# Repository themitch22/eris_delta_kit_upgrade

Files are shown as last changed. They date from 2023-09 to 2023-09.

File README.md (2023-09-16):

*********************
9/18/23
Forked design: Adding my upgraded parts to mount a new Voron V0 OLED display controller, Raspberry Pi, and an SKR Mini E3 V3 control board to run Klipper firmware.

*********************

ERIS Delta 3D Printer
=====================

ERIS is an affordable desktop 3D printer built by SeeMeCNC.  We designed this machine to be fast, easy to use and much more affordable than any of our previous designs.  

3/2/16
DIR Repetier-Firmware-092.2-ERIS is workign on prototypes

3/3/16
DIR Repetier-Firmware-092.2-ERIS-ii2dh is modified 092 firmware from UltiMachine for accelerometer probing on new hotend PCB board

####

Case fan goes to fan port 2
Hotend fan goes to fan port 1

Red motor wire to right (opposite of the USB side of mini rabmo)

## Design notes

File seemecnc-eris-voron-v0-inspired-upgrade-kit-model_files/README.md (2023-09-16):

9/18/23
Forked design: Adding my upgraded parts to mount a new Voron V0 OLED display controller, Raspberry Pi, and an SKR Mini E3 V3 control board to run Klipper firmware.

The SeeMeCNC Eris, released in 2016, was a ready to print out of the box mini delta printer made with injection molded parts and custom extruder hotend parts almost entirely US-made. They even sold these printers at retail stores like Microcenter! 

I loved this printer, but it had some major issues: 

    The ATMEGA2560 based Rambo Mini board with Repetier limits a delta printers speed and precision
    The HE280 based PCB on the effector used an accelerometer to detect nozzle probes for auto-calibration. It was a very advanced idea for 2016, but with modern firmware, delta-calibration techniques are way more reliable. For this mod, I have stuck with Manual Delta Calibration in Klipper and it's been super reliable for first layers. 
    The stock hotend and single 3010 fan was lacking. It used a bowden tube to a steel heatbreak (partially all metal) that attached the hotend to the effector PCB, the heater cartridge was a power resistor (about 20W), the single 3010 fan sucked air past the heatsync and it was also the part cooling with a shroud. The original print head did not have adequate heating and cooling.
    The Eris had no LCD controller. It had a light up logo on front which I think was supposed to be an addressable LED, but all the control was done through MatterControl (Matterhackers) so it wasn't really portable without a PC attached. 

Parts Needed and Instructions (links to vendors and files)

    Original SeeMeCNC Eris - I have not found these on ebay but there are a few still floating around or collecting dust on a shelf.
    BTT SKR Mini E3 V3 control board - It's about the same footprint as the Rambo Mini but has way more power and IO. A SKR Pico would work as well but the connectors are on the edge which might interfere with the case. You will also want an external microSD connector pass through one of the holes and stuck to the outside of the case, this helps flash board firmware from Klipper.
    SKR Mini Mounting Bracket - by w0nd4bra this bracket barely fits where the Rambo Mini use to slot in. I checked for clearance and marked and drilled two holes for M3x8 screws and used heat set inserts to fasten it to the shelf. You might want to use VHB tape instead. It will interfere with the corner screw bosses, you might have to sand that away. See the pictures for how I mounted it. 
    Raspberry Pi 3B or equivalent - These are still hard to get, you can also use the BTT Pi V1.2, the mount I designed will fit standard a Pi 3/4B, you will need to glue and heat insert the standoffs. It clips into the frame of the LCD mount backside. It provides a pass-through hole for the USB cable.
    Voron V0.2 Mini OLED Display Controller (designed by Timmit99)- This controller works with Klipper with a short USB cable to the Pi (I cut the micro USB side and soldered it to a dupont connector). You will need to print the Voron V0.2 display faceplate, knob, and diffuser (or hotglue like I used) using M2x10 self-tapping screws to mount into my custom Eris LCD mount. The LCD mount should slot right into the base like the original Eris logo. 
    E3D Revo Micro 12V kit - The Revo was the smallest, lightest, easiest hotend for the Eris. The top and base mount with M3x8 screws into the plastic. The Revo wires slip through the back side cut out. I initially worked with Hotends.com to come up with a custom mount for their J-head Farmer hotend but it was too heavy. The E3D Revo comes with a 5V fan which needs a step-down converter I just soldered into the existing whip fan connections. The current design you will need to sand down the fan shroud to not interfere with the 3010 blowers (see picture). I would also highly recommend using capricorn XS tube to reduce the long bowden issues like retraction, I can get away with 4mm retractions with this setup. Also check if you have the original EZstruder, you really want the latest SeeMeCNC EZR extruder it honestly works great as is. 
    GDSTime 3010 12V Blower Fans - These part cooling fans really make a huge difference in the performance of the Eris. My effector mount base and top has M2 x 10 screw points for mounting them and a duct that blows down on to the part (I found no need for a nozzle)
    I used the existing whip but removed the original connectors and soldered them to a 8-pin GX16 connector (Use this guide for wiring) mounted to a hole I drilled in the case, I soldered and crimped the other side of the whip to the components on the effector side. This allows you to easily remove the whole assembly for troubleshooting and travel. You will need JST-XH crimps connectors for the BTT board and maybe some dupont 2.54 pitch connectors and crimpers.

Basically if you've build a Voron V0.1/0.2 you can handle this mod. It is basically a Voron V0 delta but not nearly as rigid or fast. 

Please comment or message me and I will publish the Klipper config files needed for the Eris. 

The printing results are incredible considering the age and plastic shell of this delta. It is limited to 500mm/s2 accels and 125mm/s rapids, which is quite slow for modern standards but you can't beat the portability and looks of this little printer. 

If you have an Eris and want to do this mod, please message me I will try to help you with whatever I can. STEP files included if you need to modify something, I can provide Fusion 360 files if needed (they're too messy to publish).

Pulled files from my Printables repo:
https://www.printables.com/model/581542-seemecnc-eris-voron-v0-inspired-upgrade-kit

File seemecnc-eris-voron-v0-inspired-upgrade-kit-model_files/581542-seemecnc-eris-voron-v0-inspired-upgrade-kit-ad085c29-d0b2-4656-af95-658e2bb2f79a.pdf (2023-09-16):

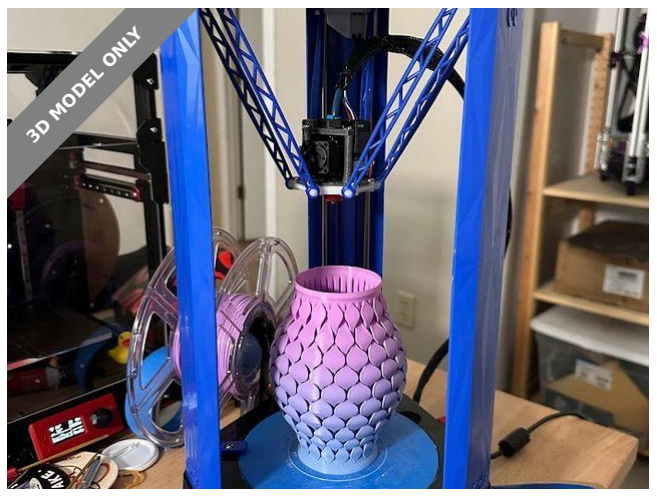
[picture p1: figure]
3D MODEL ONLY

### Summary

The ultimate upgrade package for your SeeMeCNC Eris mini delta printer (2016)

3D Printers (https://printables.com/model?categoryId=1) > Other Printer Parts & Upgrades (https://printables.com/model?categoryId=2)

Tags: raspberry | pi | eris | klipper | voron | seemecnc | v0

The SeeMeCNC Eris, (https://www.seemecnc.com/products/eris-desktop-3d-printer) released in 2016, was a ready to print out of the box mini delta printer made with injection molded parts and custom extruder hotend parts almost entirely US-made. They even sold these printers at retail stores like Microcenter!

I loved this printer, but it had some major issues:

The ATMEGA2560 based Rambo Mini board with Repetier limits a delta printers speed and precision
The HE280 based PCB on the effector used an accelerometer to detect nozzle probes for auto-calibration. It was a very advanced idea for 2016, but with modern firmware, delta-calibration techniques are way more reliable. For this mod, I have stuck with Manual Delta Calibration in Klipper and it's been super reliable for first layers.
The stock hotend and single 3010 fan was lacking. It used a bowden tube to a steel heatbreak (partially all metal) that attached the hotend to the effector PCB, the heater cartridge was a power resistor

Mitch 3D (https://printables.com/@Mitch3D)

### SeeMeCNC Eris

### Voron V0-Inspired

### Upgrade Kit

VIEW IN BROWSER (https://printables.com/model/581542-seemecnc-eris-voron-v0-inspired-upgrade-kit)

updated 13. 9. 2023 | published 13. 9. 2023

•

•

•

(about 20W), the single 3010 fan sucked air past the heatsync and it was also the part cooling with a shroud. The original print head did not have adequate heating and cooling.
The Eris had no LCD controller. It had a light up logo on front which I think was supposed to be an addressable LED, but all the control was done through MatterControl (https://www.matterhackers.com/store/l/mattercontrol/sk/MKZGTDW6) (Matterhackers) so it wasn't really portable without a PC attached.

Parts Needed and Instructions (links to vendors and files)

Original SeeMeCNC Eris - I have not found these on ebay but there are a few still floating around or collecting dust on a shelf.
BTT SKR Mini E3 V3 control board (https://biqu.equipment/products/bigtreetech-skr-mini-e3-v2-0-32-bit-control-board-for-ender-3) - It's about the same footprint as the Rambo Mini but has way more power and IO. A SKR Pico would work as well but the connectors are on the edge which might interfere with the case. You will also want an external microSD connector (https://a.co/d/5BjRwnt) pass through one of the holes and stuck to the outside of the case, this helps flash board firmware from Klipper.
SKR Mini Mounting Bracket (https://www.printables.com/model/172510-bigtreetech-skr-mini-e3-v2030-bracket) - by w0nd4bra (https://www.printables.com/@w0nd4bra) this bracket barely fits where the Rambo Mini use to slot in. I checked for clearance and marked and drilled two holes for M3x8 screws and used heat set inserts to fasten it to the shelf. You might want to use VHB tape instead. It will interfere with the corner screw bosses, you might have to sand that away. See the pictures for how I mounted it.
Raspberry Pi 3B or equivalent - These are still hard to get, you can also use the BTT Pi V1.2, the mount I designed will fit standard a Pi 3/4B, you will need to glue and heat insert the standoffs. It clips into the frame of the LCD mount backside. It provides a pass-through hole for the USB cable.
Voron V0.2 Mini OLED Display Controller (https://west3d.com/products/v0-display) (designed by Timmit99)- This controller works with Klipper with a short USB cable to the Pi (I cut the micro USB side and soldered it to a dupont connector). You will need to print the Voron V0.2 display faceplate, knob, and diffuser (https://github.com/VoronDesign/Voron-0/tree/Voron0.2r1/STLs/Display) (or hotglue like I used) using M2x10 self-tapping screws to mount into my custom Eris LCD mount. The LCD mount should slot right into the base like the original Eris logo.
E3D Revo Micro 12V kit (https://e3d-online.com/products/revo-micro) - The Revo was the smallest, lightest, easiest hotend for the Eris. The top and base mount with M3x8 screws into the plastic. The Revo wires slip through the back side cut out. I initially worked with Hotends.com to come up with a custom mount for their J-head Farmer hotend (https://hotends.com/printer-parts/hotends/j-head-farmer-hotend/) but it was too heavy. The E3D Revo comes with a 5V fan which needs a step-down converter I just soldered into the existing whip fan connections. The current design

you will need to sand down the fan shroud to not interfere

with the 3010 blowers (see picture). I would also highly
recommend using capricorn XS tube to reduce the long bowden

•

•

•

•

•

•

•

### Model files

issues like retraction, I can get away with 4mm retractions with this setup. Also check if you have the original EZstruder, you really want the latest SeeMeCNC EZR extruder (https://www.seemecnc.com/products/ezrstruder) it honestly works great as is. GDSTime 3010 12V Blower Fans (https://a.co/d/asESusC) - These part cooling fans really make a huge difference in the performance of the Eris. My effector mount base and top has M2 x 10 screw points for mounting them and a duct that blows down on to the part (I found no need for a nozzle)
I used the existing whip but removed the original connectors and soldered them to a 8-pin GX16 connector (https://a.co/d/5zVXuh1) (Use this guide for wiring) (https://hotends.com/kb/eris-3d-printer/) mounted to a hole I drilled in the case, I soldered and crimped the other side of the whip to the components on the effector side. This allows you to easily remove the whole assembly for troubleshooting and travel. You will need JST-XH crimps connectors (https://a.co/d/ebk87RT) for the BTT board and maybe some dupont 2.54 pitch connectors and crimpers.

Basically if you've build a Voron V0.1/0.2 you can handle this mod. It is basically a Voron V0 delta but not nearly as rigid or fast.

Please comment or message me and I will publish the Klipper config files needed for the Eris.
The printing results are incredible considering the age and plastic shell of this delta. It is limited to 500mm/s2 accels and 125mm/s rapids, which is quite slow for modern standards but you can't beat the portability and looks of this little printer.

If you have an Eris and want to do this mod, please message me I will try to help you with whatever I can. STEP files included if you need to modify something, I can provide Fusion 360 files if needed (they're too messy to publish).

•

•

eris-lcd-mount-pi-attachment-standoff.3mf

eris-revo-3010-effector-mount-top.3mf

### License

This work is licensed under a
Creative Commons (4.0 International License)

Attribution (http://creativecommons.org/licenses/by/4.0/)

✖ | Sharing without ATTRIBUTION
✔ | Remix Culture allowed
✔ | Commercial Use
✔ | Free Cultural Works
✔ | Meets Open Definition

eris-mini-lcd-mount.3mf

eris-lcd-mount-pi-attachment.step

eris-revo-3010-effector-mount-base.3mf

eris-mini-lcd-mount-v5.step

eris-revo-3010-effector-mount.step

eris-lcd-mount-pi-attachment-body.3mf

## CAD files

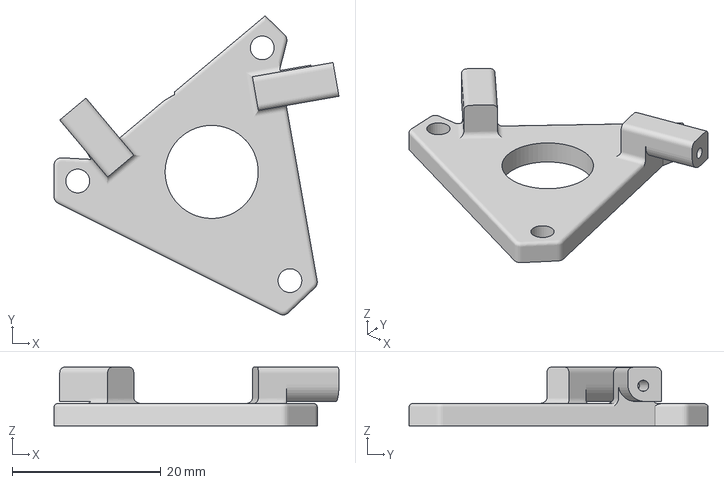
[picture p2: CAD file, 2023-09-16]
seemecnc-eris-voron-v0-inspired-upgrade-kit-model_files/Eris Revo 3010 Effector Mount Top.3mf
38.3 x 40.2 x 7.87 mm

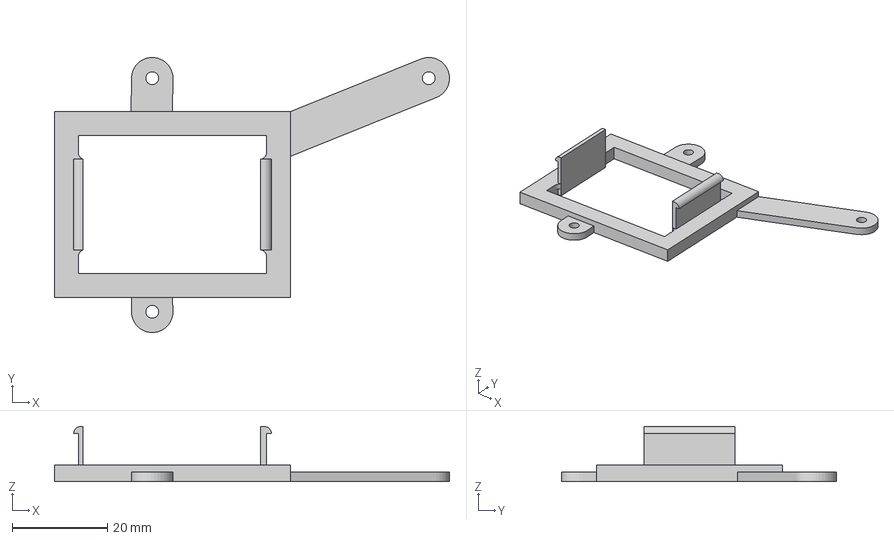
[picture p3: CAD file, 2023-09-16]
seemecnc-eris-voron-v0-inspired-upgrade-kit-model_files/Eris LCD Mount Pi Attachment Body.3mf
82.8 x 57.7 x 11.6 mm

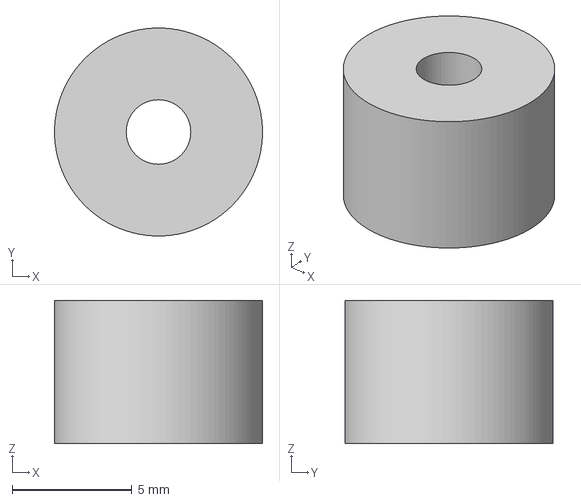
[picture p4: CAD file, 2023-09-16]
seemecnc-eris-voron-v0-inspired-upgrade-kit-model_files/Eris LCD Mount Pi Attachment Standoff.3mf
8.70 x 8.70 x 6.00 mm

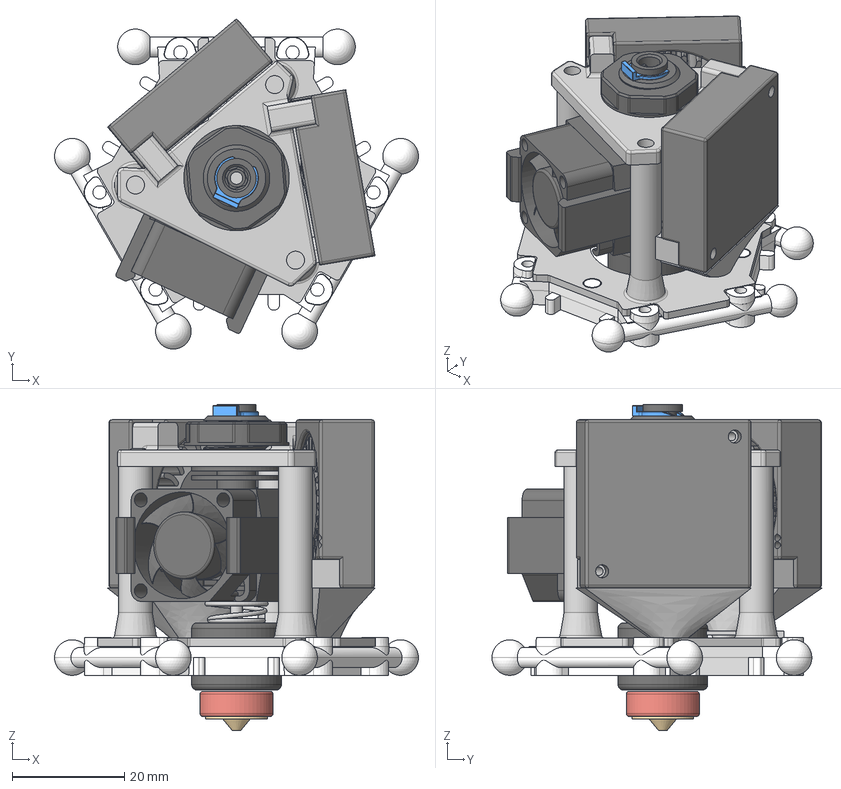
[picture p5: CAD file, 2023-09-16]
seemecnc-eris-voron-v0-inspired-upgrade-kit-model_files/Eris Revo 3010 Effector Mount.step
64.8 x 58.8 x 58.1 mm
71200 HE280 Assembly_86005 Platform
71200 HE280 Assembly_Blower 30mm x 30mm x 10mm x 2
Heatblock
Nozzle
Threaded_Nut
Spring
Heatbreak
Heatsink
Cable_Exit
Coupling_Clip
20x20x10_Fan
Fan_Mount
Coupling

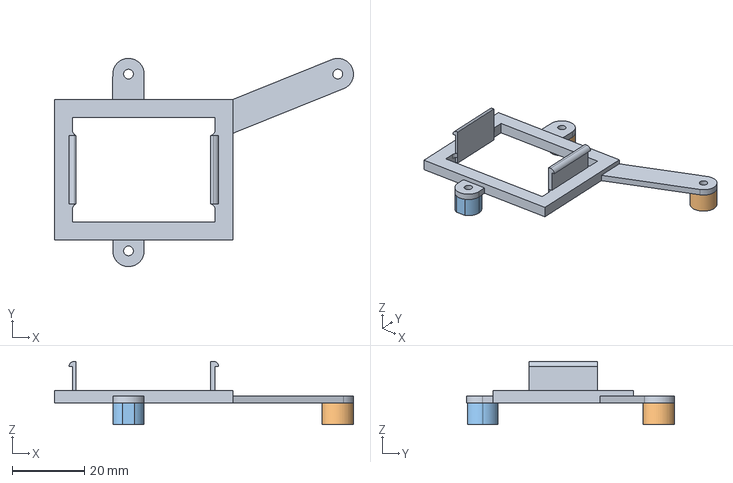
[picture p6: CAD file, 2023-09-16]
seemecnc-eris-voron-v0-inspired-upgrade-kit-model_files/Eris LCD Mount Pi Attachment.step
82.8 x 57.7 x 17.6 mm

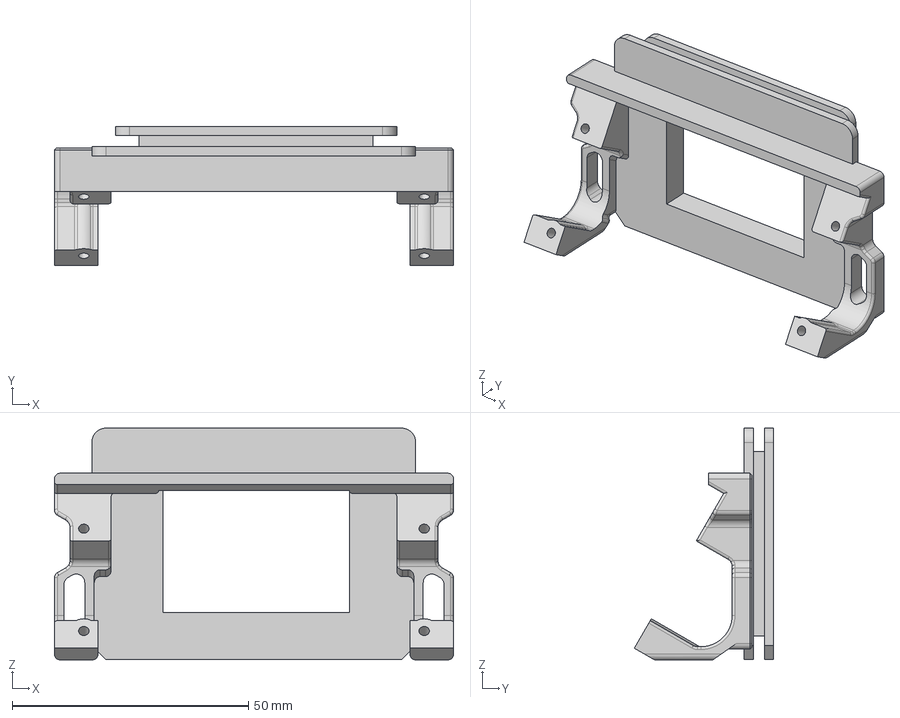
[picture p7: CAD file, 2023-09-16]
seemecnc-eris-voron-v0-inspired-upgrade-kit-model_files/Eris Mini LCD mount v5.step
84.4 x 29.5 x 49.0 mm
Display Left Foot
Display Right Foot

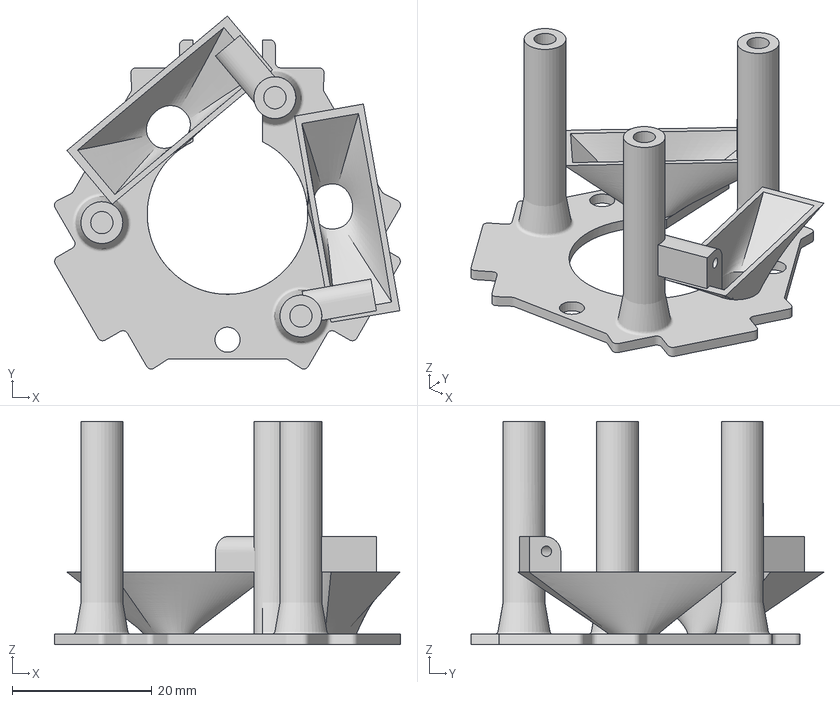
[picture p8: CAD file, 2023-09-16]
seemecnc-eris-voron-v0-inspired-upgrade-kit-model_files/Eris Revo 3010 Effector Mount Base.3mf
49.6 x 50.6 x 32.0 mm

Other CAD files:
seemecnc-eris-voron-v0-inspired-upgrade-kit-model_files/Eris Mini LCD Mount.3mf

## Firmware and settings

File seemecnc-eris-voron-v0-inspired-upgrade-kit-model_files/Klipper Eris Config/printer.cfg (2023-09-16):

# This file is an example config file for linear delta style printers.
# One may copy and edit this file to configure a new delta printer.

# DO NOT COPY THIS FILE WITHOUT CAREFULLY READING AND UPDATING IT
# FIRST. Incorrectly configured parameters may cause damage.

# See docs/Config_Reference.md for a description of parameters.

# ================= Eris Repetier Specs ======================
#define DELTA_DIAGONAL_ROD 134.9  // 134.58 early measurement
#define DELTA_MAX_RADIUS 65  // max printable area allowed by firmware
#define PRINTER_RADIUS 98.38  //PRINTER_RADIUS-END_EFFECTOR_HORIZONTAL_OFFSET-CARRIAGE_HORIZONTAL_OFFSET
#define Z_MAX_LENGTH 175.0
#define END_EFFECTOR_HORIZONTAL_OFFSET 23.38
#define CARRIAGE_HORIZONTAL_OFFSET 10

[include mainsail.cfg]


#[include Display_macros.cfg]
#[include Display_config.cfg]
[include V0Display.cfg]
#[include menu.cfg]

[stepper_a]
step_pin: PB13
dir_pin: PB12
enable_pin: !PB14
microsteps: 16
rotation_distance: 40
endstop_pin: PC0
homing_speed: 80
#position_endstop: 190
#arm_length: 134.9

[tmc2209 stepper_a]
uart_pin: PC11
tx_pin: PC10
uart_address: 0
run_current: 0.8
#run_current: 0.580
hold_current: 0.500
stealthchop_threshold: 999999

[stepper_b]
step_pin: PB10
dir_pin: PB2
enable_pin: !PB11
microsteps: 16
rotation_distance: 40
endstop_pin: PC1
homing_speed: 80

[tmc2209 stepper_b]
uart_pin: PC11
tx_pin: PC10
uart_address: 2
run_current: 0.8
#run_current: 0.580
hold_current: 0.500
stealthchop_threshold: 999999

[stepper_c]
step_pin: PB0
dir_pin: PC5
enable_pin: !PB1
microsteps: 16
rotation_distance: 40
endstop_pin: PC2
homing_speed: 80

[tmc2209 stepper_c]
uart_pin: PC11
tx_pin: PC10
uart_address: 1
run_current: 0.8
#run_current: 0.580
hold_current: 0.500
stealthchop_threshold: 999999

[extruder]
step_pin: PB3
dir_pin: !PB4
enable_pin: !PD1
microsteps: 16
rotation_distance: 33.500
nozzle_diameter: 0.400
filament_diameter: 1.750
heater_pin: PC8
sensor_type: ATC Semitec 104NT-4-R025H42G
sensor_pin: PA0
#control: pid
#pid_Kp: 21.527
#pid_Ki: 1.063
#pid_Kd: 108.982
min_temp: 0
max_temp: 250

[tmc2209 extruder]
uart_pin: PC11
tx_pin: PC10
uart_address: 3
run_current: 0.650
hold_current: 0.500
stealthchop_threshold: 999999

[mcu]
serial: #insert USB serial ID here

[printer]
kinematics: delta
max_velocity: 100
max_accel: 500
max_z_velocity: 100
minimum_z_position=-5
#delta_radius: 65

[delta_calibrate]
radius: 50

[heater_fan extruder]
pin: PC6

[fan]
pin: PB15

[controller_fan extruder]
pin: PC7

#*# <---------------------- SAVE_CONFIG ---------------------->
#*# DO NOT EDIT THIS BLOCK OR BELOW. The contents are auto-generated.
#*#
#*# [printer]
#*# delta_radius = 64.914350
#*#
#*# [stepper_a]
#*# angle = 210.223311
#*# arm_length = 134.900000
#*# position_endstop = 188.003345
#*#
#*# [stepper_b]
#*# angle = 329.538410
#*# arm_length = 134.900000
#*# position_endstop = 185.081668
#*#
#*# [stepper_c]
#*# angle = 90.000000
#*# arm_length = 134.900000
#*# position_endstop = 186.740133
#*#
#*# [extruder]
#*# control = pid
#*# pid_kp = 34.465
#*# pid_ki = 4.995
#*# pid_kd = 59.452
#*#
#*# [delta_calibrate]
#*# height0 = 0.0
#*# height0_pos = 15041.000,14806.000,14939.000
#*# height1 = 0.0
#*# height1_pos = 17070.000,16847.000,13698.000
#*# height2 = 0.0
#*# height2_pos = 14748.000,18009.000,14641.000
#*# height3 = 0.0
#*# height3_pos = 13859.000,16485.000,16634.000
#*# height4 = 0.0
#*# height4_pos = 14689.000,14447.000,17148.000
#*# height5 = 0.0
#*# height5_pos = 16438.000,13700.000,16342.000
#*# height6 = 0.0
#*# height6_pos = 17716.000,14487.000,14608.000

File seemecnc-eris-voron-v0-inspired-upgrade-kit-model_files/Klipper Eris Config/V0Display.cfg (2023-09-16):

[mcu display]
serial: /dev/serial/by-id/usb-Klipper_stm32f042x6_18000B000643303756353720-if00
restart_method: command

[display]
lcd_type: sh1106
i2c_mcu: display
i2c_bus: i2c1a
encoder_pins: ^display:PA3, ^display:PA4
click_pin: ^!display:PA1
kill_pin: ^!display:PA5
x_offset: 2

[neopixel displayStatus]
pin: display:PA0
chain_count: 1
color_order: GRB
initial_RED: 0.24
initial_GREEN: 0
initial_BLUE: 0.18

[menu __main __setup __calib __delta_calib_man]
type: list
#enable: {(not printer.idle_timeout.state == "Printing") and ('delta_calibrate' in printer)}
name: Delta cal. man
[menu __main __setup __calib __delta_calib_man __start]
type: command
name: Start probing
gcode:
    G28
    DELTA_CALIBRATE METHOD=manual

[menu __main __setup __calib __delta_calib_man __move_z]
type: input
name: Move Z: {'%03.2f' % menu.input}
input: {printer.gcode_move.gcode_position.z}
input_step: 1
realtime: True
gcode:
    {%- if menu.event == 'change' -%}
        G1 Z{'%.2f' % menu.input}
    {%- elif menu.event == 'long_click' -%}
        G1 Z{'%.2f' % menu.input}
        SAVE_GCODE_STATE NAME=__move__axis
        G91
        G1 Z2
        G1 Z-2
        RESTORE_GCODE_STATE NAME=__move__axis
    {%- endif -%}

[menu __main __setup __calib __delta_calib_man __test_z]
type: input
name: Test Z: {['++','+','+.01','+.05','+.1','+.5','-.5','-.1','-.05','-.01','-','--'][menu.input|int]}
input: 6
input_min: 0
input_max: 11
input_step: 1
gcode:
    {%- if menu.event == 'long_click' -%}
        TESTZ Z={['++','+','+.01','+.05','+.1','+.5','-.5','-.1','-.05','-.01','-','--'][menu.input|int]}
    {%- endif -%}

[menu __main __setup __calib __delta_calib_man __accept]
type: command
name: Accept
gcode: ACCEPT

[menu __main __setup __calib __delta_calib_man __abort]
type: command
name: Abort
gcode: ABORT

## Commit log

2023-09-16 Added step and 3mf files for the parts designed
    Pulled from my Printables.com https://www.printables.com/model/581542-seemecnc-eris-voron-v0-inspired-upgrade-kit/files
    [Eris LCD Mount Pi Attachment Body.3mf, Eris LCD Mount Pi Attachment Standoff.3mf, Eris LCD Mount Pi Attachment.step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]
2023-09-16 added readme with instructions and bom
2023-09-16 Added Klipper config for the Eris
    [printer.cfg]
2023-09-16 Add V0 display config
    [V0Display.cfg]
2023-09-16 removed my USB serial ID
    [printer.cfg]
